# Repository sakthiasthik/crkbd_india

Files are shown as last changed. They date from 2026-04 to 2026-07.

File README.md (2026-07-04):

# Corne Indian ⌨️

A split mechanical keyboard **inspired by the original [CRKBD (Corne)](https://github.com/foostan/crkbd)** by [foostan](https://github.com/foostan). While the overall keyboard layout, key positions, and form factor follow the Corne design, the **entire schematic and PCB layout have been redesigned from scratch**.

The hardware has been engineered with a focus on the **Indian maker ecosystem**, using components that are readily available from Indian suppliers. The PCB has been designed to simplify manufacturing, assembly, troubleshooting, and long-term maintenance. If a component fails, it can be replaced easily without requiring hard-to-source imported parts — making the keyboard highly repairable and practical for everyday use.

---

## Highlights

- **Inspired by the CRKBD (Corne) split keyboard design**
- **Complete schematic designed from scratch**
- **Complete PCB layout designed from scratch**
- **Powered by RP2040** — affordable, powerful, and widely available in India (replaces the Pro Micro / ATmega32U4)
- **Hot-swappable switches** — no soldering required for switches
- Optimized for components that are **easily available from Indian suppliers**
- Designed for **easy manufacturing and assembly**
- Simplified **rework and repair** with accessible component placement
- **Fully open-source hardware** — anyone can build, modify, and maintain

---

## Design Files

All design files are in [`pcbs/corne-indian/`](pcbs/corne-indian/):

```
pcbs/corne-indian/corne-inidan-hotswap/
├── corne-inidan-hotswap.kicad_pro    # KiCad project
├── corne-inidan-hotswap.kicad_sch    # Main schematic
├── corne-inidan-hotswap.kicad_pcb    # PCB layout
├── left.kicad_sch                    # Left half schematic
├── right.kicad_sch                   # Right half schematic
├── corne-inidan-hotswap.step         # 3D model
└── corne_ibom.html                   # Interactive BOM
```

> Designed in **KiCad**. Open the `.kicad_pro` file to get started.

---

## Images

### Original CRKBD (Corne) — The Inspiration

crkbd-cherry
crkbd-chocolate

### Corne Indian — Our Design

<!-- TODO: Add Corne Indian PCB render (top view) -->
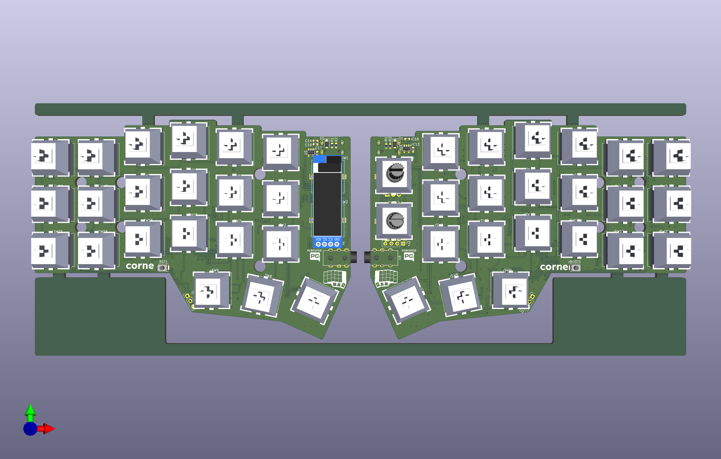
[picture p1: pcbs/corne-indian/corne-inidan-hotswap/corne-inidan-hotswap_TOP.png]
Corne Indian PCB Top


<!-- TODO: Add Corne Indian PCB render (bottom view) -->
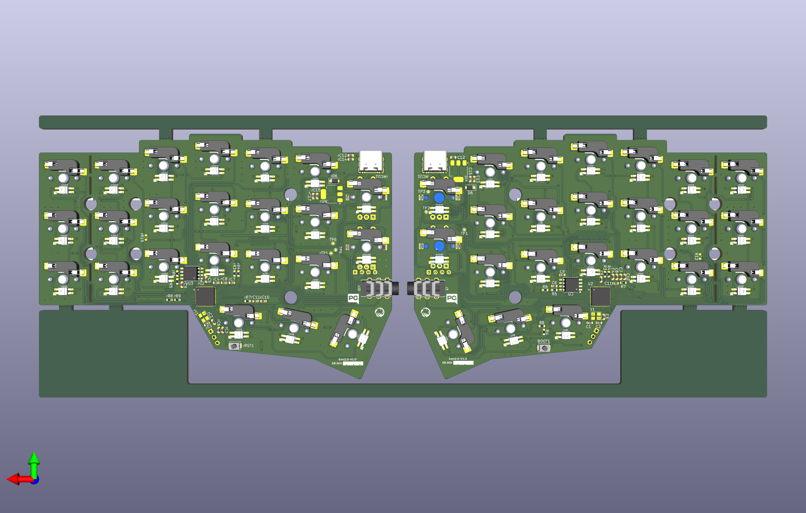
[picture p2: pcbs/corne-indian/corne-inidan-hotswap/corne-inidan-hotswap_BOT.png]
Corne Indian PCB Bottom


<!-- TODO: Add assembled Corne Indian keyboard photo -->
Corne Indian Assembled

<!-- TODO: Add Corne Indian 3D render -->
<!-- [Corne Indian 3D Render](https://via.placeholder.com/800x600/0f3460/e0e0e0?text=Corne+Indian+-+3D+Render) -->

---

## Comparison: Original CRKBD vs Corne Indian

| Feature | Original CRKBD | Corne Indian |
|---|---|---|
| **Microcontroller** | Pro Micro (ATmega32U4) | RP2040 |
| **Switch mounting** | Soldered / Hotswap | Hot-swappable |
| **Component sourcing** | International | India-focused |
| **Schematic** | Original by foostan | Redesigned from scratch |
| **PCB Layout** | Original by foostan | Redesigned from scratch |
| **License** | MIT | MIT |

---

## Credits

This project stands on the shoulders of the excellent **[CRKBD (Corne)](https://github.com/foostan/crkbd)** by **foostan**. The Corne Indian retains the same split-keyboard layout and form factor that makes the Corne great, while re-engineering the hardware for the Indian maker community.

---

## License

This project is licensed under the **MIT License** — see [LICENSE](LICENSE) for details.

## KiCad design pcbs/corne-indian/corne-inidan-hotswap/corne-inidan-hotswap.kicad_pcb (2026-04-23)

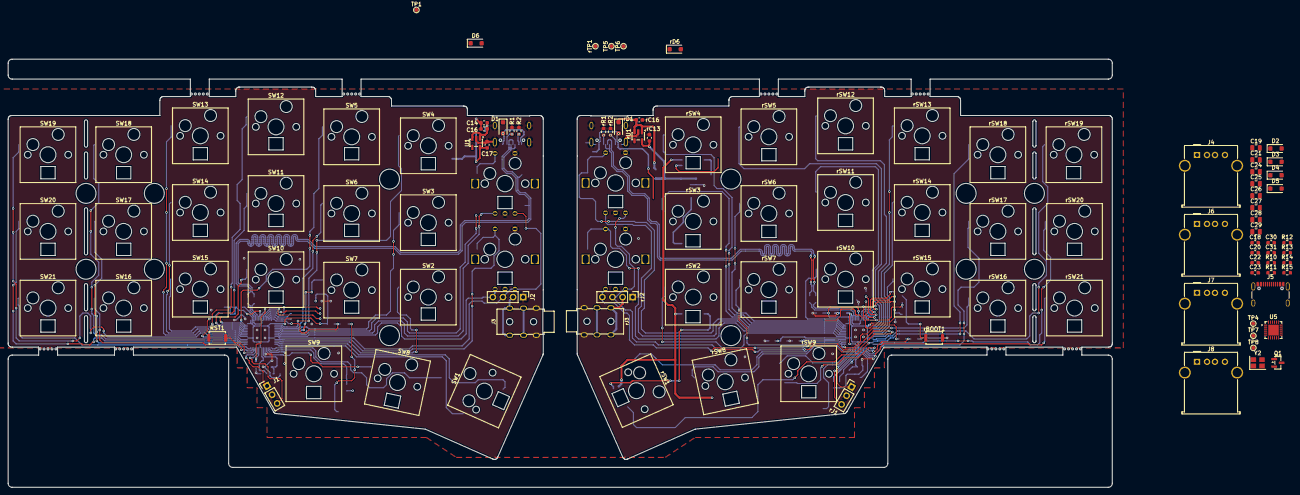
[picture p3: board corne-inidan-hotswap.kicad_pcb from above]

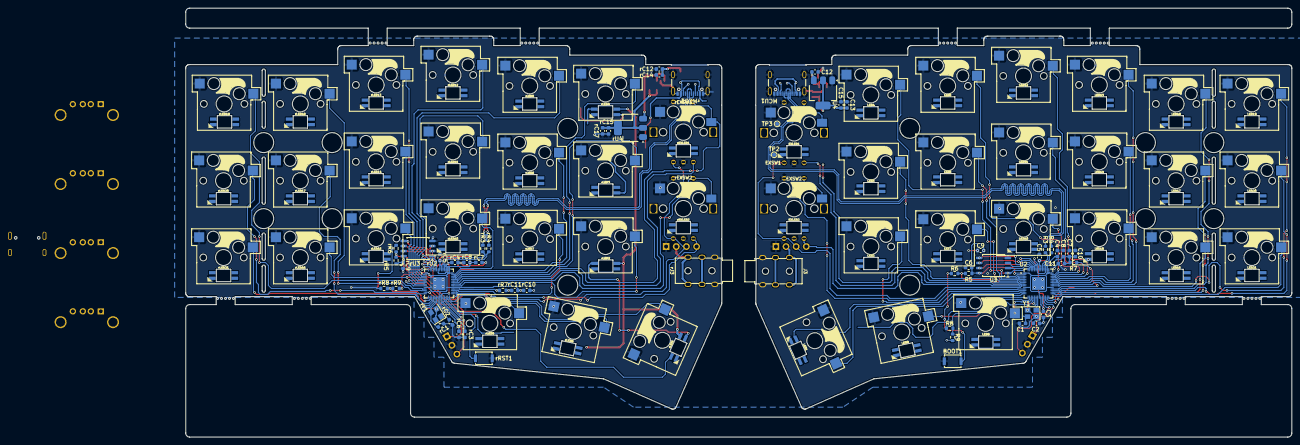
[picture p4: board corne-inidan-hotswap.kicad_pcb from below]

Board: 2 copper layers, 277.2 x 107.5 mm, 211 parts (107 on the bottom side), 171 nets.

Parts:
BOOT1: SKRKAGE020; SW_Push_SPST_NO_Alps_SKRK
C1, C2, C30, C31: 20pf; C_0603_1608Metric
C3, C4, C5, C6, C7, C8, C9, C10, C11, C12, C13, C14, C15, C18, C20, C22, C23: 100nf; C_0603_1608Metric
C16, C17: 10uf; C_0603_1608Metric
C19, C21, C24, C25, C26, C27, C28, C29: 10uf; C_0805_2012Metric
D1, D2, D3, D4, D5, D6: DSK34; D_SOD-123F
EXLED1, EXLED2: SK6812MINI-E; YS-SK6812MINI-E
EXSW1, EXSW2: RotaryEncoder_Switch; keyswitch_cherrymx_hotswap_1u_rotary_encoder_ec12
J1: Conn_01x03_Pin; PinHeader_1x03_P2.54mm_Vertical
J2: Conn_01x04_Pin; PinHeader_1x04_P2.54mm_Vertical
J3: PJ-3136-B
J4, J6, J7, J8: USB_A; USB_A_Molex_67643_Horizontal
J5: USB4105 - Type C USB 2.0 Connector; USB_C_Receptacle_GCT_USB4105-xx-A_16P_TopMnt_Horizontal
LED1, LED2, LED3, LED4, LED5, LED6, LED7, LED8, LED9, LED10, LED11, LED12, LED13, LED14, LED15, LED16, LED17, LED18, LED19, LED20, LED21: SK6812MINI-E; YS-SK6812MINI-E
MCU1: USB4105 - Type C USB 2.0 Connector; USB_C_Receptacle_GCT_USB4105-xx-A_16P_TopMnt_Horizontal
Q1: SI2301; SOT-23
R1, R2, R10, R11: 5K1; R_0603_1608Metric
R3, R4: 27R; R_0603_1608Metric
R5, R7, R8, R13, R14: 10K; R_0603_1608Metric
R6: 1K; R_0603_1608Metric
R9, R12: 5K6; R_0603_1608Metric
R15: 0R/DNP; R_0603_1608Metric
RST1: SKRKAGE020; SW_Push_SPST_NO_Alps_SKRK
SW1: SW_Push; SW_Cherry_MX_1.50u_Hotswap
SW2, SW3, SW4, SW5, SW6, SW7, SW8, SW9, SW10, SW11, SW12, SW13, SW14, SW15, SW16, SW17, SW18, SW19, SW20, SW21: SW_Push; SW_Cherry_MX_1.00u_Hotswap
TP1, TP2, TP3, TP4, TP5, TP6, TP7, TP8: TestPoint; TestPoint_Pad_D1.0mm
U1: AP2127K-3.3; SOT-23-5
U2: RP2040; QFN-56-1EP_7x7mm_P0.4mm_EP3.2x3.2mm
U3: W25Q32JVSS; SOIC-8_5.3x5.3mm_P1.27mm
U4: AMS1117-3.3; SOT-223-3_TabPin2
U5: CH334F; QFN-24-1EP_4x4mm_P0.5mm_EP2.7x2.7mm
Y1, Y2: 12Mhz; Crystal_SMD_Abracon_ABM8AIG-4Pin_3.2x2.5mm
rBOOT1: SKRKAGE020; SW_Push_SPST_NO_Alps_SKRK
rC1, rC2: 20pf; C_0603_1608Metric
rC3, rC4, rC5, rC6, rC7, rC8, rC9, rC10, rC11, rC12, rC13, rC14, rC15: 100nf; C_0603_1608Metric
rC16, rC17: 10uf; C_0603_1608Metric
rD1, rD6: DSK34; D_SOD-123F
rEXLED1, rEXLED2: SK6812MINI-E; YS-SK6812MINI-E
rEXSW1, rEXSW2: RotaryEncoder_Switch; keyswitch_cherrymx_hotswap_1u_rotary_encoder_ec12
rJ1: Conn_01x03_Pin; PinHeader_1x03_P2.54mm_Vertical
rJ2: Conn_01x04_Pin; PinHeader_1x04_P2.54mm_Vertical
rJ3: PJ-3136-B
rLED1, rLED2, rLED3, rLED4, rLED5, rLED6, rLED7, rLED8, rLED9, rLED10, rLED11, rLED12, rLED13, rLED14, rLED15, rLED16, rLED17, rLED18, rLED19, rLED20, rLED21: SK6812MINI-E; YS-SK6812MINI-E
rMCU1: USB4105 - Type C USB 2.0 Connector; USB_C_Receptacle_GCT_USB4105-xx-A_16P_TopMnt_Horizontal
rR1, rR2: 5K1; R_0603_1608Metric
rR3, rR4: 27R; R_0603_1608Metric
rR5, rR7, rR8: 10K; R_0603_1608Metric
rR6: 1K; R_0603_1608Metric
rR9: 5K6; R_0603_1608Metric
rRST1: SKRKAGE020; SW_Push_SPST_NO_Alps_SKRK
rSW1: SW_Push; SW_Cherry_MX_1.50u_Hotswap
rSW2, rSW3, rSW4, rSW5, rSW6, rSW7, rSW8, rSW9, rSW10, rSW11, rSW12, rSW13, rSW14, rSW15, rSW16, rSW17, rSW18, rSW19, rSW20, rSW21: SW_Push; SW_Cherry_MX_1.00u_Hotswap
rTP1: TestPoint; TestPoint_Pad_D1.0mm
rU1: AP2127K-3.3; SOT-23-5
rU2: RP2040; QFN-56-1EP_7x7mm_P0.4mm_EP3.2x3.2mm
rU3: W25Q32JVSS; SOIC-8_5.3x5.3mm_P1.27mm
rU4: AMS1117-3.3; SOT-223-3_TabPin2
rY1: 12Mhz; Crystal_SMD_Abracon_ABM8AIG-4Pin_3.2x2.5mm

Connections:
+3.3V: C5.2, C6.2, C7.2, C8.2, C9.2, C10.2, C11.2, C13.2, C15.2, C17.2, R5.1, R7.2, U1.5 (VOUT), U2.1 (IOVDD), U2.10 (IOVDD), U2.22 (IOVDD), U2.33 (IOVDD), U2.42 (IOVDD), U2.43 (ADC_AVDD), U2.44 (VREG_IN), U2.48 (USB_VDD), U2.49 (IOVDD), U3.8 (VCC), U4.2 (VO), rC5.2, rC6.2, rC7.2, rC8.2, rC9.2, rC10.2, rC11.2, rC13.2, rC15.2, rC17.2, rR5.1, rU1.5 (VOUT), rU2.1 (IOVDD), rU2.10 (IOVDD), rU2.22 (IOVDD), rU2.33 (IOVDD), rU2.42 (IOVDD), rU2.43 (ADC_AVDD), rU2.44 (VREG_IN), rU2.48 (USB_VDD), rU2.49 (IOVDD), rU3.8 (VCC), rU4.2 (VO)
+5V: C12.2, C14.2, C16.2, D1.1 (K), D6.2 (A), J2.2, J3.T, U1.1 (VIN), U1.3 (EN), U4.3 (VI), rC12.2, rC14.2, rC16.2, rD1.1 (K), rD6.2 (A), rJ2.2, rJ3.T, rU1.1 (VIN), rU1.3 (EN), rU4.3 (VI)
/Right/5V_L: rD6.1 (K), rEXLED1.1 (VDD), rEXLED2.1 (VDD), rLED1.1 (VDD), rLED2.1 (VDD), rLED3.1 (VDD), rLED4.1 (VDD), rLED5.1 (VDD), rLED6.1 (VDD), rLED7.1 (VDD), rLED8.1 (VDD), rLED9.1 (VDD), rLED10.1 (VDD), rLED11.1 (VDD), rLED12.1 (VDD), rLED13.1 (VDD), rLED14.1 (VDD), rLED15.1 (VDD), rLED16.1 (VDD), rLED17.1 (VDD), rLED18.1 (VDD), rLED19.1 (VDD), rLED20.1 (VDD), rLED21.1 (VDD)
/Right/BOOT: rBOOT1.1, rR6.2
/Right/D+: rR3.2, rU2.47 (USB_DP)
/Right/D-: rR4.2, rU2.46 (USB_DM)
/Right/KEY_1: rSW1.1, rU2.30 (GPIO19)
/Right/KEY_2: rSW2.1, rU2.34 (GPIO22)
/Right/KEY_3: rSW3.1, rU2.38 (GPIO26_ADC0)
/Right/KEY_4: rSW4.1, rU2.39 (GPIO27_ADC1)
/Right/KEY_5: rSW5.1, rU2.3 (GPIO1)
/Right/KEY_6: rSW6.1, rU2.40 (GPIO28_ADC2)
/Right/KEY_7: rSW7.1, rU2.31 (GPIO20)
/Right/KEY_8: rSW8.1, rU2.28 (GPIO17)
/Right/KEY_9: rSW9.1, rU2.27 (GPIO16)
/Right/KEY_10: rSW10.1, rU2.41 (GPIO29_ADC3)
/Right/KEY_11: rSW11.1, rU2.2 (GPIO0)
/Right/KEY_12: rSW12.1, rU2.4 (GPIO2)
/Right/KEY_13: rSW13.1, rU2.5 (GPIO3)
/Right/KEY_14: rSW14.1, rU2.6 (GPIO4)
/Right/KEY_15: rSW15.1, rU2.7 (GPIO5)
/Right/KEY_16: rSW16.1, rU2.29 (GPIO18)
/Right/KEY_17: rSW17.1, rU2.17 (GPIO14)
/Right/KEY_18: rSW18.1, rU2.12 (GPIO9)
/Right/KEY_19: rSW19.1, rU2.11 (GPIO8)
/Right/KEY_20: rSW20.1, rU2.14 (GPIO11)
/Right/KEY_21: rSW21.1, rU2.18 (GPIO15)
/Right/KEY_EX1: rEXSW1.S2, rU2.37 (GPIO25)
/Right/KEY_EX2: rEXSW2.S2, rU2.35 (GPIO23)
/Right/L_KEY: rLED1.4 (DIN), rU2.13 (GPIO10)
/Right/L_KEY2: rLED1.2 (DOUT), rLED2.4 (DIN)
/Right/L_KEY3: rLED2.2 (DOUT), rLED3.4 (DIN)
/Right/L_KEY4: rLED3.2 (DOUT), rLED4.4 (DIN)
/Right/L_KEY5: rLED4.2 (DOUT), rLED5.4 (DIN)
/Right/L_KEY6: rLED5.2 (DOUT), rLED6.4 (DIN)
/Right/L_KEY7: rLED6.2 (DOUT), rLED7.4 (DIN)
/Right/L_KEY8: rLED7.2 (DOUT), rLED8.4 (DIN)
/Right/L_KEY9: rLED8.2 (DOUT), rLED9.4 (DIN)
/Right/L_KEY10: rLED9.2 (DOUT), rLED10.4 (DIN)
/Right/L_KEY11: rLED10.2 (DOUT), rLED11.4 (DIN)
/Right/L_KEY12: rLED11.2 (DOUT), rLED12.4 (DIN)
/Right/L_KEY13: rLED12.2 (DOUT), rLED13.4 (DIN)
/Right/L_KEY14: rLED13.2 (DOUT), rLED14.4 (DIN)
/Right/L_KEY15: rLED14.2 (DOUT), rLED15.4 (DIN)
/Right/L_KEY16: rLED15.2 (DOUT), rLED16.4 (DIN)
/Right/L_KEY17: rLED16.2 (DOUT), rLED17.4 (DIN)
/Right/L_KEY18: rLED17.2 (DOUT), rLED18.4 (DIN)
/Right/L_KEY19: rLED18.2 (DOUT), rLED19.4 (DIN)
/Right/L_KEY20: rLED19.2 (DOUT), rLED20.4 (DIN)
/Right/L_KEY21: rLED20.2 (DOUT), rLED21.4 (DIN)
/Right/L_KEY22: rEXLED1.4 (DIN), rLED21.2 (DOUT)
/Right/L_KEY23: rEXLED1.2 (DOUT), rEXLED2.4 (DIN)
/Right/RE0A: rEXSW1.A, rU2.36 (GPIO24)
/Right/RE1A: rEXSW2.A, rJ2.4, rU2.8 (GPIO6)
/Right/REB: rEXSW1.B, rEXSW2.B, rJ2.3, rU2.9 (GPIO7)
/Right/RESET: rRST1.1, rU2.26 (RUN)
/Right/SCLK: rU2.52 (QSPI_SCLK), rU3.6 (CLK)
/Right/SD0: rU2.53 (QSPI_SD0), rU3.5 (DI/IO_{0})
/Right/SD1: rU2.55 (QSPI_SD1), rU3.2 (DO/IO_{1})
/Right/SD2: rU2.54 (QSPI_SD2), rU3.3 (~WP/IO_{2})
/Right/SD3: rU2.51 (QSPI_SD3), rU3.7 (~HOLD/~RESET/IO_{3})
/Right/SS: rR5.2, rR6.1, rU2.56 (QSPI_SS), rU3.1 (~CS)
/Right/SWCLK: rJ1.3, rU2.24 (SWCLK)
/Right/SWDIO: rJ1.1, rU2.25 (SWD)
/Right/TX: rJ3.R, rU2.15 (GPIO12)
/Right/USB_VBUS_PIN: rR8.2, rR9.1, rU2.16 (GPIO13)
/Right/U_+: TP6.1, rMCU1.A6 (D+), rMCU1.B6 (D+), rR3.1
/Right/U_-: TP5.1, rMCU1.A7 (D-), rMCU1.B7 (D-), rR4.1
/USB_HUB/5V: J5.A4 (VBUS), J5.A9 (VBUS), J5.B4 (VBUS), J5.B9 (VBUS), Q1.2 (S), R15.2, TP4.1
/USB_HUB/J1_+: J4.3 (D+), U5.12 (DP1+)
/USB_HUB/J1_-: J4.2 (D-), U5.11 (DM1-)
/USB_HUB/J2_+: J6.3 (D+), U5.10 (DP2+)
/USB_HUB/J2_-: J6.2 (D-), U5.9 (DM2-)
/USB_HUB/J3_+: J7.3 (D+), U5.8 (DP3+)
/USB_HUB/J3_-: J7.2 (D-), U5.7 (DM3-)
/USB_HUB/J4_+: J8.3 (D+), U5.6 (DP4+)
/USB_HUB/J4_-: J8.2 (D-), U5.5 (DM4-)
/USB_HUB/USB_VBUS_PIN: R12.1, R13.2
/USB_HUB/U_+: J5.A6 (D+), J5.B6 (D+), TP8.1, U5.15 (DPU+)
/USB_HUB/U_-: J5.A7 (D-), J5.B7 (D-), TP7.1, U5.14 (DMU-)
/left/5V_L: D6.1 (K), EXLED1.1 (VDD), EXLED2.1 (VDD), LED1.1 (VDD), LED2.1 (VDD), LED3.1 (VDD), LED4.1 (VDD), LED5.1 (VDD), LED6.1 (VDD), LED7.1 (VDD), LED8.1 (VDD), LED9.1 (VDD), LED10.1 (VDD), LED11.1 (VDD), LED12.1 (VDD), LED13.1 (VDD), LED14.1 (VDD), LED15.1 (VDD), LED16.1 (VDD), LED17.1 (VDD), LED18.1 (VDD), LED19.1 (VDD), LED20.1 (VDD), LED21.1 (VDD)
/left/BOOT: BOOT1.1, R6.2
/left/D+: R3.2, U2.47 (USB_DP)
/left/D-: R4.2, U2.46 (USB_DM)
/left/KEY_1: SW1.1, U2.14 (GPIO11)
/left/KEY_2: SW2.1, U2.12 (GPIO9)
/left/KEY_3: SW3.1, U2.4 (GPIO2)
/left/KEY_4: SW4.1, U2.2 (GPIO0)
/left/KEY_5: SW5.1, U2.41 (GPIO29_ADC3)
/left/KEY_6: SW6.1, U2.3 (GPIO1)
/left/KEY_7: SW7.1, U2.5 (GPIO3)
/left/KEY_8: SW8.1, U2.18 (GPIO15)
/left/KEY_9: SW9.1, U2.17 (GPIO14)
/left/KEY_10: SW10.1, U2.40 (GPIO28_ADC2)
/left/KEY_11: SW11.1, U2.39 (GPIO27_ADC1)
/left/KEY_12: SW12.1, U2.38 (GPIO26_ADC0)
/left/KEY_13: SW13.1, U2.35 (GPIO23)
/left/KEY_14: SW14.1, U2.36 (GPIO24)
/left/KEY_15: SW15.1, U2.37 (GPIO25)
/left/KEY_16: SW16.1, U2.27 (GPIO16)
/left/KEY_17: SW17.1, U2.29 (GPIO18)
/left/KEY_18: SW18.1, U2.31 (GPIO20)
/left/KEY_19: SW19.1, U2.34 (GPIO22)
/left/KEY_20: SW20.1, U2.30 (GPIO19)
/left/KEY_21: SW21.1, U2.28 (GPIO17)
/left/KEY_EX1: EXSW1.S2, U2.6 (GPIO4)
/left/KEY_EX2: EXSW2.S2, U2.11 (GPIO8)
/left/L_KEY: LED1.4 (DIN), U2.13 (GPIO10)
/left/L_KEY2: LED1.2 (DOUT), LED2.4 (DIN)
/left/L_KEY3: LED2.2 (DOUT), LED3.4 (DIN)
/left/L_KEY4: LED3.2 (DOUT), LED5.4 (DIN)
/left/L_KEY5: LED4.4 (DIN), LED5.2 (DOUT)
/left/L_KEY6: LED4.2 (DOUT), LED6.4 (DIN)
/left/L_KEY7: LED6.2 (DOUT), LED7.4 (DIN)
/left/L_KEY8: LED7.2 (DOUT), LED8.4 (DIN)
/left/L_KEY9: LED8.2 (DOUT), LED9.4 (DIN)
/left/L_KEY10: LED9.2 (DOUT), LED10.4 (DIN)
/left/L_KEY11: LED10.2 (DOUT), LED11.4 (DIN)
/left/L_KEY12: LED11.2 (DOUT), LED12.4 (DIN)
/left/L_KEY13: LED12.2 (DOUT), LED13.4 (DIN)
/left/L_KEY14: LED13.2 (DOUT), LED14.4 (DIN)
/left/L_KEY15: LED14.2 (DOUT), LED15.4 (DIN)
/left/L_KEY16: LED15.2 (DOUT), LED16.4 (DIN)
/left/L_KEY17: LED16.2 (DOUT), LED17.4 (DIN)
/left/L_KEY18: LED17.2 (DOUT), LED18.4 (DIN)
/left/L_KEY19: LED18.2 (DOUT), LED19.4 (DIN)
/left/L_KEY20: LED19.2 (DOUT), LED20.4 (DIN)
/left/L_KEY21: LED20.2 (DOUT), LED21.4 (DIN)
/left/L_KEY22: EXLED1.4 (DIN), LED21.2 (DOUT)
/left/L_KEY23: EXLED1.2 (DOUT), EXLED2.4 (DIN)
/left/RE0A: EXSW1.A, U2.7 (GPIO5)
/left/RE1A: EXSW2.A, J2.4, U2.8 (GPIO6)
/left/REB: EXSW1.B, EXSW2.B, J2.3, U2.9 (GPIO7)
/left/RESET: RST1.1, U2.26 (RUN)
/left/SCLK: U2.52 (QSPI_SCLK), U3.6 (CLK)
/left/SD0: U2.53 (QSPI_SD0), U3.5 (DI/IO_{0})
/left/SD1: U2.55 (QSPI_SD1), U3.2 (DO/IO_{1})
/left/SD2: U2.54 (QSPI_SD2), U3.3 (~WP/IO_{2})
/left/SD3: U2.51 (QSPI_SD3), U3.7 (~HOLD/~RESET/IO_{3})
/left/SS: R5.2, R6.1, U2.56 (QSPI_SS), U3.1 (~CS)
/left/SWCLK: J1.3, U2.24 (SWCLK)
/left/SWDIO: J1.1, U2.25 (SWD)
/left/TX: J3.R, U2.15 (GPIO12)
/left/USB_VBUS_PIN: R8.2, R9.1, U2.16 (GPIO13)
/left/U_+: MCU1.A6 (D+), MCU1.B6 (D+), R3.1, TP3.1
/left/U_-: MCU1.A7 (D-), MCU1.B7 (D-), R4.1, TP2.1
GND: BOOT1.2, C1.1, C2.1, C3.1, C4.1, C5.1, C6.1, C7.1, C8.1, C9.1, C10.1, C11.1, C12.1, C13.1, C14.1, C15.1, C16.1, C17.1, C18.1, C19.1, C20.1, C21.1, C22.1, C23.1, C24.1, C25.1, C26.1, C27.1, C28.1, C29.1, C30.1, C31.1, EXLED1.3 (VSS), EXLED2.3 (VSS), EXSW1.C, EXSW1.S1, EXSW2.C, EXSW2.S1, J1.2, J2.1, J3.S, J4.4 (GND), J4.5 (Shield), J5.A1 (GND), J5.A12 (GND), J5.B1 (GND), J5.B12 (GND), J5.S1 (SHIELD), J6.4 (GND), J6.5 (Shield), J7.4 (GND), J7.5 (Shield), J8.4 (GND), J8.5 (Shield), LED1.3 (VSS), LED2.3 (VSS), LED3.3 (VSS), LED4.3 (VSS), LED5.3 (VSS), LED6.3 (VSS), LED7.3 (VSS), LED8.3 (VSS), LED9.3 (VSS), LED10.3 (VSS), LED11.3 (VSS), LED12.3 (VSS), LED13.3 (VSS), LED14.3 (VSS), LED15.3 (VSS), LED16.3 (VSS), LED17.3 (VSS), LED18.3 (VSS), LED19.3 (VSS), LED20.3 (VSS), LED21.3 (VSS), MCU1.A1 (GND), MCU1.A12 (GND), MCU1.B1 (GND), MCU1.B12 (GND), MCU1.S1 (SHIELD), R1.2, R2.2, R8.1, R10.2, R11.2, R13.1, R14.2, RST1.2, SW1.2, SW2.2, SW3.2, SW4.2, SW5.2, SW6.2, SW7.2, SW8.2, SW9.2, SW10.2, SW11.2, SW12.2, SW13.2, SW14.2, SW15.2, SW16.2, SW17.2, SW18.2, SW19.2, SW20.2, SW21.2, U1.2 (GND), U2.19 (TESTEN), U2.57 (GND), U3.4 (GND), U4.1 (GND), U5.25 (GND), Y1.2, Y1.4, Y2.2, Y2.4, rBOOT1.2, rC1.1, rC2.1, rC3.1, rC4.1, rC5.1, rC6.1, rC7.1, rC8.1, rC9.1, rC10.1, rC11.1, rC12.1, rC13.1, rC14.1, rC15.1, rC16.1, rC17.1, rEXLED1.3 (VSS), rEXLED2.3 (VSS), rEXSW1.C, rEXSW1.S1, rEXSW2.C, rEXSW2.S1, rJ1.2, rJ2.1, rJ3.S, rLED1.3 (VSS), rLED2.3 (VSS), rLED3.3 (VSS), rLED4.3 (VSS), rLED5.3 (VSS), rLED6.3 (VSS), rLED7.3 (VSS), rLED8.3 (VSS), rLED9.3 (VSS), rLED10.3 (VSS), rLED11.3 (VSS), rLED12.3 (VSS), rLED13.3 (VSS), rLED14.3 (VSS), rLED15.3 (VSS), rLED16.3 (VSS), rLED17.3 (VSS), rLED18.3 (VSS), rLED19.3 (VSS), rLED20.3 (VSS), rLED21.3 (VSS), rMCU1.A1 (GND), rMCU1.A12 (GND), rMCU1.B1 (GND), rMCU1.B12 (GND), rMCU1.S1 (SHIELD), rR1.2, rR2.2, rR7.2, rR8.1, rRST1.2, rSW1.2, rSW2.2, rSW3.2, rSW4.2, rSW5.2, rSW6.2, rSW7.2, rSW8.2, rSW9.2, rSW10.2, rSW11.2, rSW12.2, rSW13.2, rSW14.2, rSW15.2, rSW16.2, rSW17.2, rSW18.2, rSW19.2, rSW20.2, rSW21.2, rU1.2 (GND), rU2.19 (TESTEN), rU2.57 (GND), rU3.4 (GND), rU4.1 (GND), rY1.2, rY1.4
H+3.3V: C28.2, C29.2, U5.20 (VDD33_{LDO})
H+5V: C26.2, C27.2, D2.2 (A), D3.2 (A), D4.2 (A), D5.2 (A), Q1.3 (D), R15.1, U5.19 (V5)
unnamed: C18.2, C19.2, D2.1 (K), J4.1 (VBUS)
unnamed: C20.2, C21.2, D3.1 (K), J6.1 (VBUS)
unnamed: C22.2, C24.2, D4.1 (K), J7.1 (VBUS)
unnamed: C23.2, C25.2, D5.1 (K), J8.1 (VBUS)
unnamed: J5.A5 (CC1), R10.1
unnamed: J5.B5 (CC2), R11.1
unnamed: MCU1.A5 (CC1), R1.1
unnamed: MCU1.B5 (CC2), R2.1
unnamed: Q1.1 (G), R14.1
unnamed: R7.1, U2.32 (GPIO21)
unnamed: C3.2, C4.2, U2.23 (DVDD), U2.45 (VREG_VOUT), U2.50 (DVDD)
unnamed: C1.2, U2.20 (XIN), Y1.3
unnamed: C2.2, U2.21 (XOUT), Y1.1
unnamed: C31.2, U5.4 (XI), Y2.1
unnamed: C30.2, U5.3 (XO), Y2.3
unnamed: rMCU1.A5 (CC1), rR1.1
unnamed: rMCU1.B5 (CC2), rR2.1
unnamed: rR7.1, rU2.32 (GPIO21)
unnamed: rC3.2, rC4.2, rU2.23 (DVDD), rU2.45 (VREG_VOUT), rU2.50 (DVDD)
unnamed: rC1.2, rU2.20 (XIN), rY1.3
unnamed: rC2.2, rU2.21 (XOUT), rY1.1
VBUS: D1.2 (A), MCU1.A4 (VBUS), MCU1.A9 (VBUS), MCU1.B4 (VBUS), MCU1.B9 (VBUS), R9.2, TP1.1, rD1.2 (A), rMCU1.A4 (VBUS), rMCU1.A9 (VBUS), rMCU1.B4 (VBUS), rMCU1.B9 (VBUS), rR9.2, rTP1.1

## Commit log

2026-04-16 Planning to change the Layout & Key based on components avilability on the India
    [corne-inidan-hotswap.kicad_pcb, corne-inidan-hotswap.kicad_sch, left.kicad_sch]
2026-04-16 Left side LED & switch schematic added But need to check
    [left.kicad_sch]
2026-04-16 Schematic is Done for Right side But Only switch & LED & placement
    [Right.kicad_sch, corne-inidan-hotswap.kicad_pcb, corne-inidan-hotswap.kicad_sch]
2026-04-17 Rp2040 added to the shematic need to map to all Key Switch pins
    [Right.kicad_sch, corne-inidan-hotswap.kicad_pcb, left.kicad_sch]
2026-04-17 Mid of the renumbering & renaming
    [Right.kicad_sch, corne-inidan-hotswap.kicad_pcb, left.kicad_sch]
2026-04-19 Mid of the Placement still Rotary encoder is not done
    [Right.kicad_sch, corne-inidan-hotswap.kicad_pcb, left.kicad_sch]
2026-04-20 Mid of the Component placement still the Rotarty nob is not done
    [Right.kicad_sch, USB_HUB.kicad_sch, corne-inidan-hotswap.kicad_pcb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]
2026-04-20 Rotart encode also added in PCB layout
    [Right.kicad_sch, corne-inidan-hotswap.kicad_pcb, left.kicad_sch]
2026-04-22 Mid of the Layout
    [Right.kicad_sch, corne-inidan-hotswap.kicad_pcb, left.kicad_sch]
2026-04-22 Mid of the routing
    [corne-inidan-hotswap.kicad_pcb]
2026-04-23 Still layouting & mid of the Routing is going on
    [corne-inidan-hotswap.kicad_pcb]
2026-04-23 Mid of the Routing almost done for Switch & then Still LED not started
    [Right.kicad_sch, corne-inidan-hotswap.kicad_pcb, left.kicad_sch]
2026-04-24 left side Layout of the Keyboard is done
    Partial side of the right design is also Done
    [Right.kicad_sch]
2026-04-26 Design almost done for routing some changes in the footprint
    [left.kicad_sch]
2026-04-26 PCB Footprint updated
2026-04-26 PCB Layout is almost done Cosmetic Chnages need to do
    [Right.kicad_sch, left.kicad_sch]
2026-04-28 USB Hub design updated
    [USB_HUB.kicad_sch]
2026-04-29 USB Circuit deleted & Design is also compeleted in LAyout level
    [Right.kicad_sch, USB_HUB.kicad_sch, left.kicad_sch]
2026-04-29 Double check with corne is also schematic apart from esd diode reset is done
    [corne-inidan-hotswap.kicad_sch]
2026-07-04 Rewrite README for Corne Indian project
    Replaced the original CRKBD README with project-specific content:
    - Describes Corne Indian as a from-scratch redesign inspired by CRKBD
    - Highlights RP2040, hot-swap, India-sourced components
    - Lists design files and project structure
    - Preserves original CRKBD images with attribution
    - Adds placeholders for Corne Indian PCB/assembly photos
    - Includes comparison table and credits section
2026-07-04 Add Corne Indian PCB images and update README
    - Replace placeholder images with actual PCB renders (top/bottom)
    - Add assembled keyboard photo (Fullworking.jpg)
    - Include interactive BOM (corne_ibom.html)
